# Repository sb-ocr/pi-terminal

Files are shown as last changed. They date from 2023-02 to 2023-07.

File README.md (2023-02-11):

# Pi Terminal

Watch the build video ↓

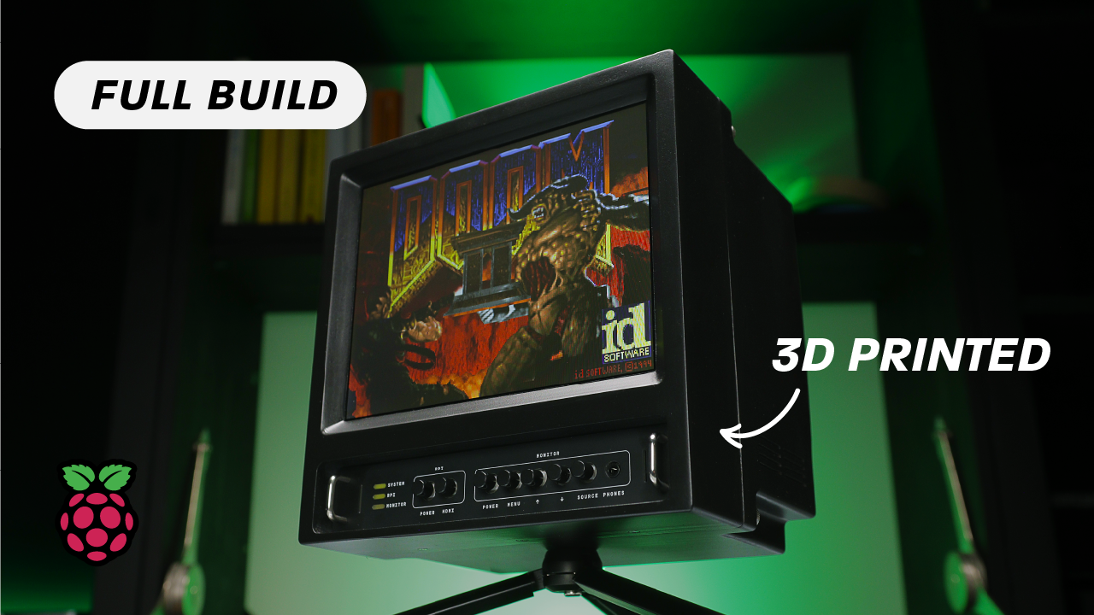
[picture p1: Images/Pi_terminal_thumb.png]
[](https://youtu.be/-QD0J8EfYqw)

Pi _Terminal is an all-in-one portable enclosure for the Raspberry Pi 4, featuring a 8 inch IPS screen, a low profile ice tower cooler, a UPS using two rechargeable 18650 lithium batteries and a HDMI switcher to use the display on it's own as a monitor.

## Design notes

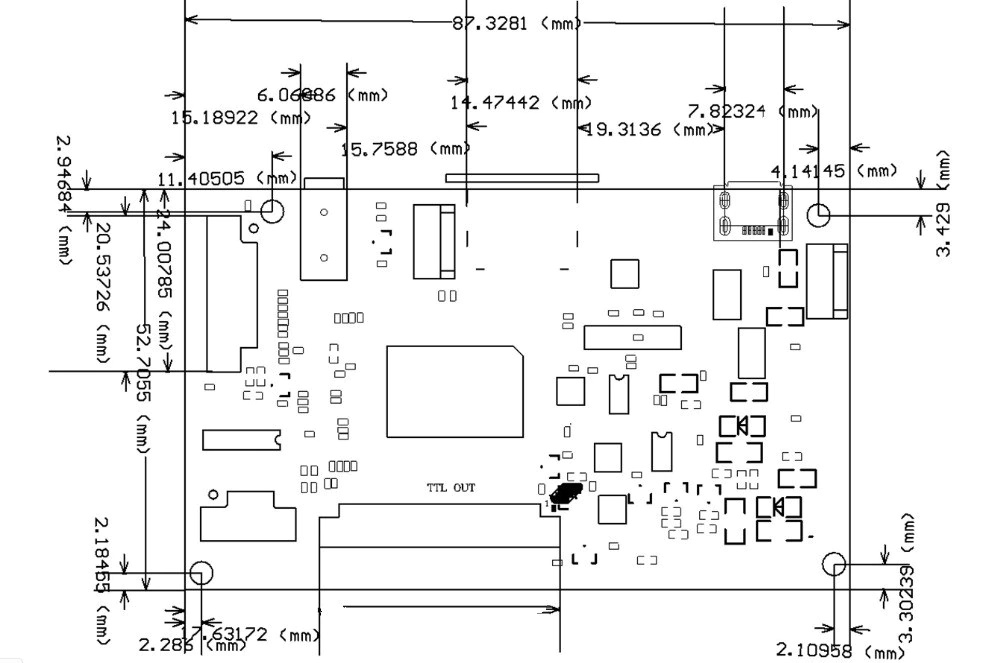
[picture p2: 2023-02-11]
Resources/Datasheets/Electronics/H08c82881f7de49e3b5ddad9591e3e27cJ.jpg

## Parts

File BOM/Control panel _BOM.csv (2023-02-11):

Qty | Value | Device | Package | Parts | Description | Manufacturer Part # | Digikey
2 | 100 Ohms | R-US_CHIP-0603(1608-METRIC) | RESC1608X60 | R1, R2 | Resistor Fixed - ANSI | WR06X101 JTL | 1292-WR06X101JTLCT-ND
2 | 4 Ohms | OWS142550TA4 | OWS-142550TA-4 | SPK1, SPK2 | 4 Ohms IoT Speaker Speaker 2 W 980 Hz ~ 20 kHz Top Rectangular | OWS-142550TA-4 | 3949-OWS-142550TA-4-ND
1 | - | PVA2EEH11.7NV2 | PVA2 | SW7 | Pushbutton Switch DPDT Keyswitch Through Hole | PVA2EEH1 1.7N V2 | 108-PVA2EEH11.7NV2-ND
6 | - | PVA1OAH11.2NV2 | PVA1 | SW1, SW2, SW3, SW4, SW5, SW6 | Pushbutton Switch DPST-NO Keyswitch Through Hole | PVA1 OA H1 1.2N V2 | 401-1133-ND
3 | - | CHIP-FLAT-G_1206 | LEDC3216X75N_FLAT-G | D1, D2, D3 | Green 567nm LED Indication - Discrete 2.1V 1206 (3016 Metric) | PG1101W-TR | 404-1046-1-ND
2 | - | STX-3790-5NSTX-3790-5N_KYC | STX-3790-5N_KYC | J1, J2 | 3.50mm (0.141", 1/8", Mini Plug) - Headphone Phone Jack Stereo (3 Conductor, TRS) Connector Solder | STX-3790-5N | 2092-STX-3790-5N-ND
1 | - | PINHD-2X10 | 2X10 | JP1 | Connector Header Through Hole 20 position 0.100" (2.54mm) | PREC010DAAN-RC | S2012EC-10-ND
1 |  | PINHD-2X2 | 2X2 | JP2 | Connector Header Through Hole 4 position 0.100" (2.54mm) | PREC002DAAN-RC | S2012EC-02-ND
7 | Black |  |  |  | Round Keyswitch Switch Cap Black Snap Fit | PV BK | 401-1148-ND

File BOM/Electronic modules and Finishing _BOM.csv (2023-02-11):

Qty | Item | Link | Link (alt)
Electronics
1 | Raspberry Pi 4 | https://rpilocator.com/
1 | Raspberry Pi Low-Profile CPU Cooler | https://geni.us/jZGuZt9
1 | Pi-UpTime UPS 2.0 | https://geni.us/zOOjE
2 | 2 × unprotected 18650 Li-Ion — 3400mAh
1 | IPS LCD 8 inch HJ080IA-01E with Driver Board | https://geni.us/ZfU1Y | https://s.click.aliexpress.com/e/_DmC2qmH
1 | HDMI Switcher 2 in 1 Out | https://geni.us/OfXlV
 | Hook-up wire | https://geni.us/8hiS
 | Dupont Connectors | https://geni.us/AMdor
1 | Micro HDMI to Standard Plug | https://www.adafruit.com/product/3557 | https://s.click.aliexpress.com/e/_DeT0a9b
1 | Micro HDMI to Standard Socket | https://www.adafruit.com/product/3557 | https://s.click.aliexpress.com/e/_DeT0a9b
1 | Standard HDMI Plug to Socket | https://www.adafruit.com/product/3557 | https://s.click.aliexpress.com/e/_DeT0a9b
1 | Standard HDMI Plug to Plug | https://www.adafruit.com/product/3557 | https://s.click.aliexpress.com/e/_DeT0a9b
1 | Micro to Micro USB cable (short)
1 | 3.5mm Audio cable (short)
Finishing
1 | Spool of PLA | https://geni.us/XkGsy
 | Assorted Grits Sandpaper | https://geni.us/turnM3
 | Glazing and Spot Putty | https://geni.us/3jiw9
 | Filler Primer (sandable) | https://geni.us/1BAKZ
 | Spray Paint | https://geni.us/I7qjJ
 | ‎Flat Matte Clear Coat | https://geni.us/Cywvbo

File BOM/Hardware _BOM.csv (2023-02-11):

Quantity | Description | McMaster Carr # | Amazon
1 | Heat-Set Inserts for Plastic 1/4"-20 Thread Size, 0.3" Installed Length, Brass | 93365A160
8 | Heat-Set Inserts for Plastic Brass, M4 x 0.70 mm Thread Size, 7.900 mm Installed Length | 94180A353
21 | Heat-Set Inserts for Plastic Brass, M2.5 x 0.45 mm Thread Size, 3.4 mm Installed Length | 94180A321
2 | Round Pull Handle 304 Stainless Steel, 3/4" Mounting Hole Center-to-Center Width, 1/2" Projection | 1726A112
4 | Flared-Collar Knurled-Head Thumb Screw M4 x 0.70 mm Thread Size, 10 mm Long | 99607A276
13 | Socket Head Screw M2.5 x 0.45 mm Thread, 5 mm Long | 91292A009 | https://geni.us/t4BmSQ
5 | Socket Head Screw M2.5 x 0.45 mm Thread, 20 mm Long | 91292A019 | https://geni.us/t4BmSQ
3 | Socket Head Screw M2.5 x 0.45 mm Thread, 8 mm Long | 91292A012 | https://geni.us/t4BmSQ
3 | Flat Head M2.5 x 5 - 6 mm Long | 93395A173
 | M2.5 Nylon Spacer Standoffs |  | https://geni.us/jIyiM

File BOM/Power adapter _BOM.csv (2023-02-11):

Qty | Value | Device | Package | Parts | Description | Manufacturer Part # | Digikey
2 |  | USB4125-GF-A_REVA2 | GCT_USB4125-GF-A_REVA2 | J1, J2 | USB-C (USB TYPE-C) Receptacle Connector 24 (6+18 Dummy) Charging only | USB4125-GF-A | 2073-USB4125-GF-ACT-ND
1 |  | 10118192-0002LF | AMPHENOL_10118192-0002LF | J3 | USB - micro B USB 2.0 Receptacle Connector 5 Position Surface Mount, Right Angle | 10118192-0002LF | 609-5379-1-ND
1 |  | PINHD-1X2 | 1X2 | JP1 | Connector Header Through Hole 2 position 0.100" (2.54mm) | PREC002SAAN-RC | S1012EC-02-ND
2 | 5K1 | R-US_CHIP-0603(1608-METRIC) | RESC1608X60 | R1, R2 | 5.1 kOhms ±5% 0.1W, 1/10W Chip Resistor 0603 (1608 Metric) | RC0603JR-075K1L | 311-5.1KGRCT-ND
1 |  | 2828XX-2282837-2 | TERMBLK_508-2N | U1 | 2 Position Wire to Board Terminal Block Horizontal with Board | 282837-2 | A113320-ND
1 |  | SPST |  |  | Rocker Switch SPST 6A (AC) 125 V Panel Mount, Snap-In | PRK22J5BBBNN | CH864-ND
1 |  | 1 x 2 |  |  | Shunt Connector Black Open Top 0.100" (2.54mm) Gold | QPC02SXGN-RC | S9337-ND

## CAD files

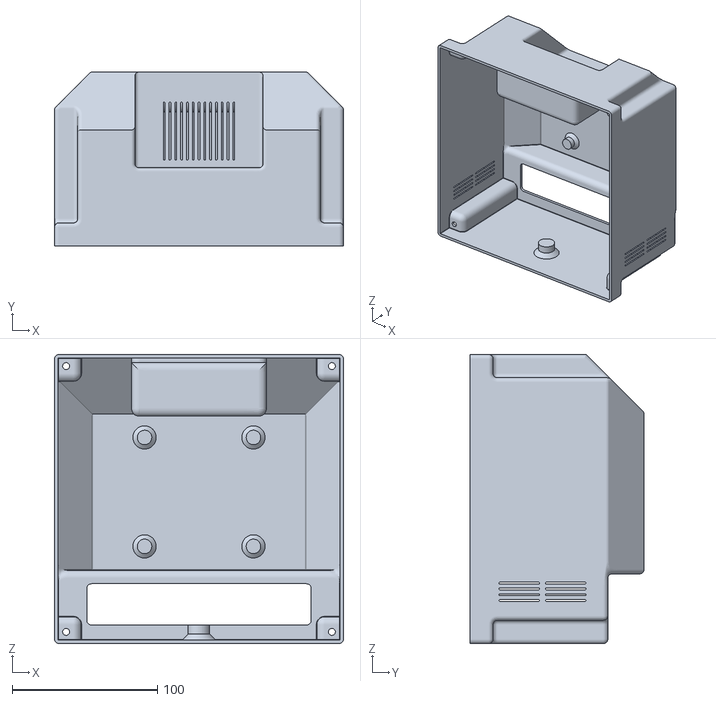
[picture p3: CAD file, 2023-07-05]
STLs/Back Shell.stl
199.0 x 120.0 x 199.0

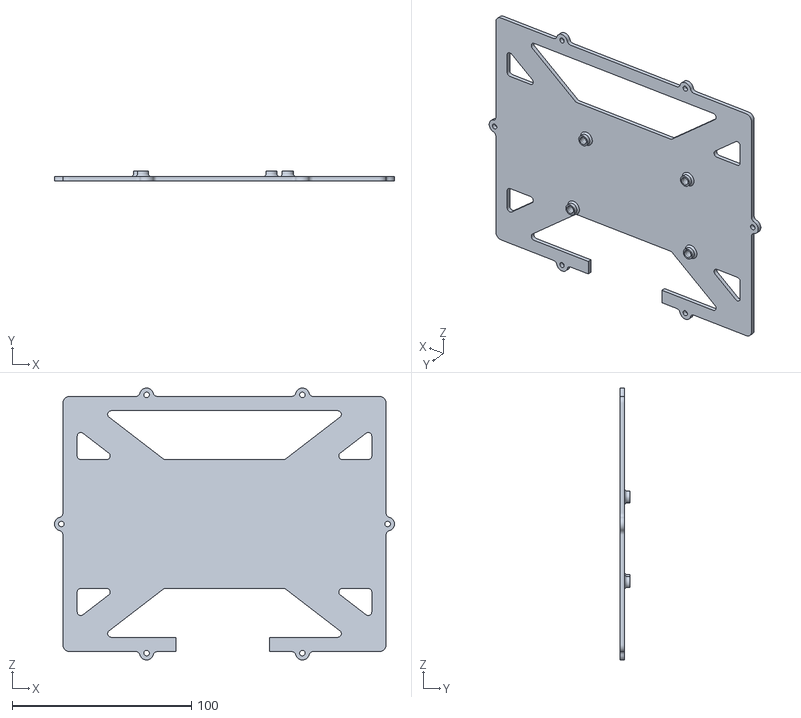
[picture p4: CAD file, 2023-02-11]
STLs/Screen Back Plate.stl
189.9 x 5.40 x 151.9

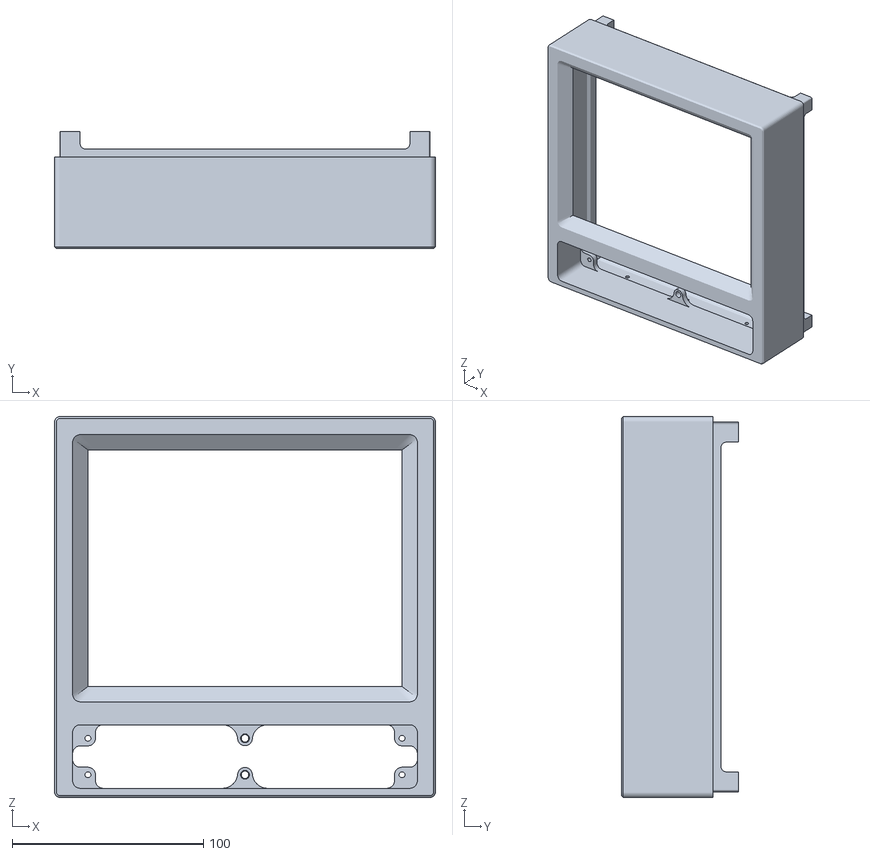
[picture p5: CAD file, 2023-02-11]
STLs/Front Bezel.stl
199.0 x 61.4 x 199.0

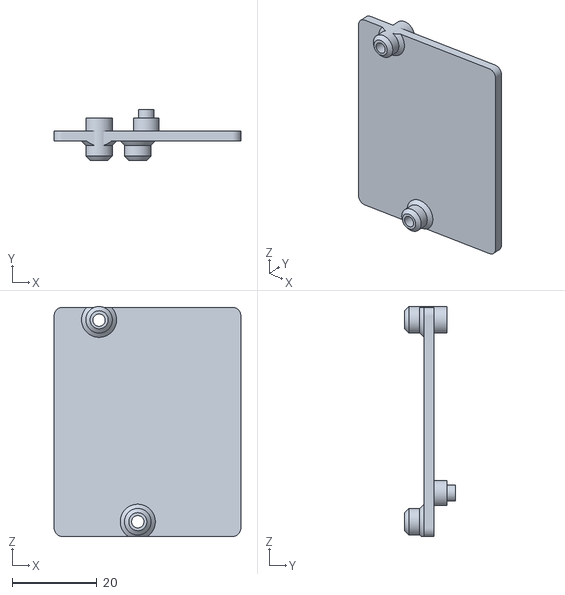
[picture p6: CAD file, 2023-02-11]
STLs/HDMI Switch Plate.stl
44.0 x 11.9 x 54.2

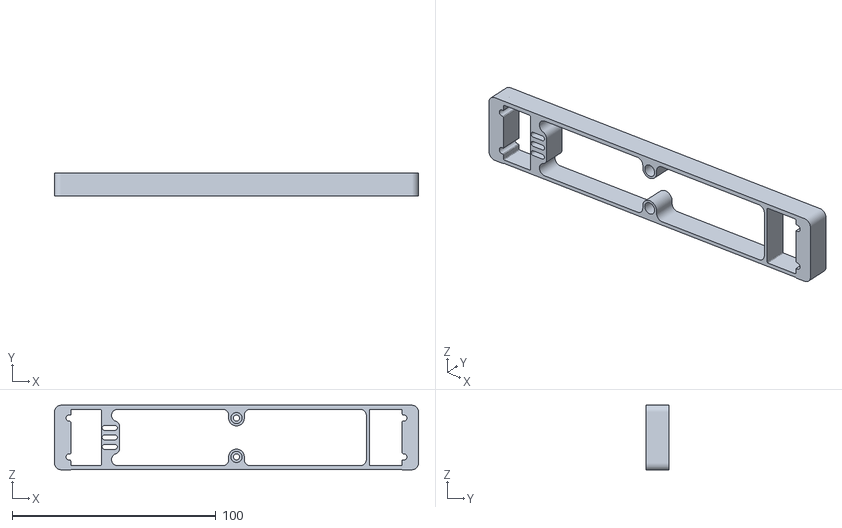
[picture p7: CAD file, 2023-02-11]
STLs/Control Panel Support.stl
178.5 x 11.1 x 31.7

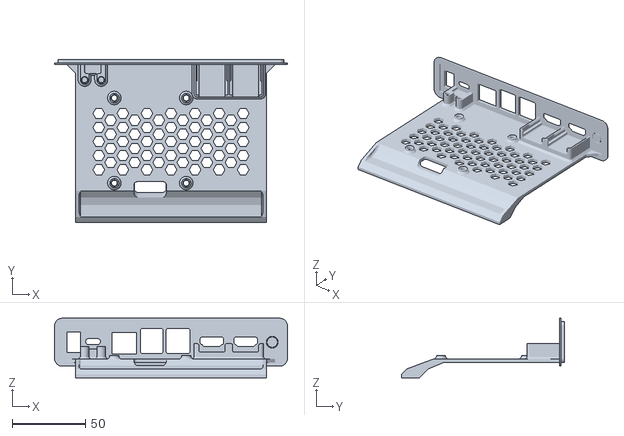
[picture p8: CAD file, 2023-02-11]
STLs/PCB and IO Plate.stl
158.8 x 111.4 x 40.6

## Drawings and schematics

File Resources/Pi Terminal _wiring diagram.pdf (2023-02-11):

11

10

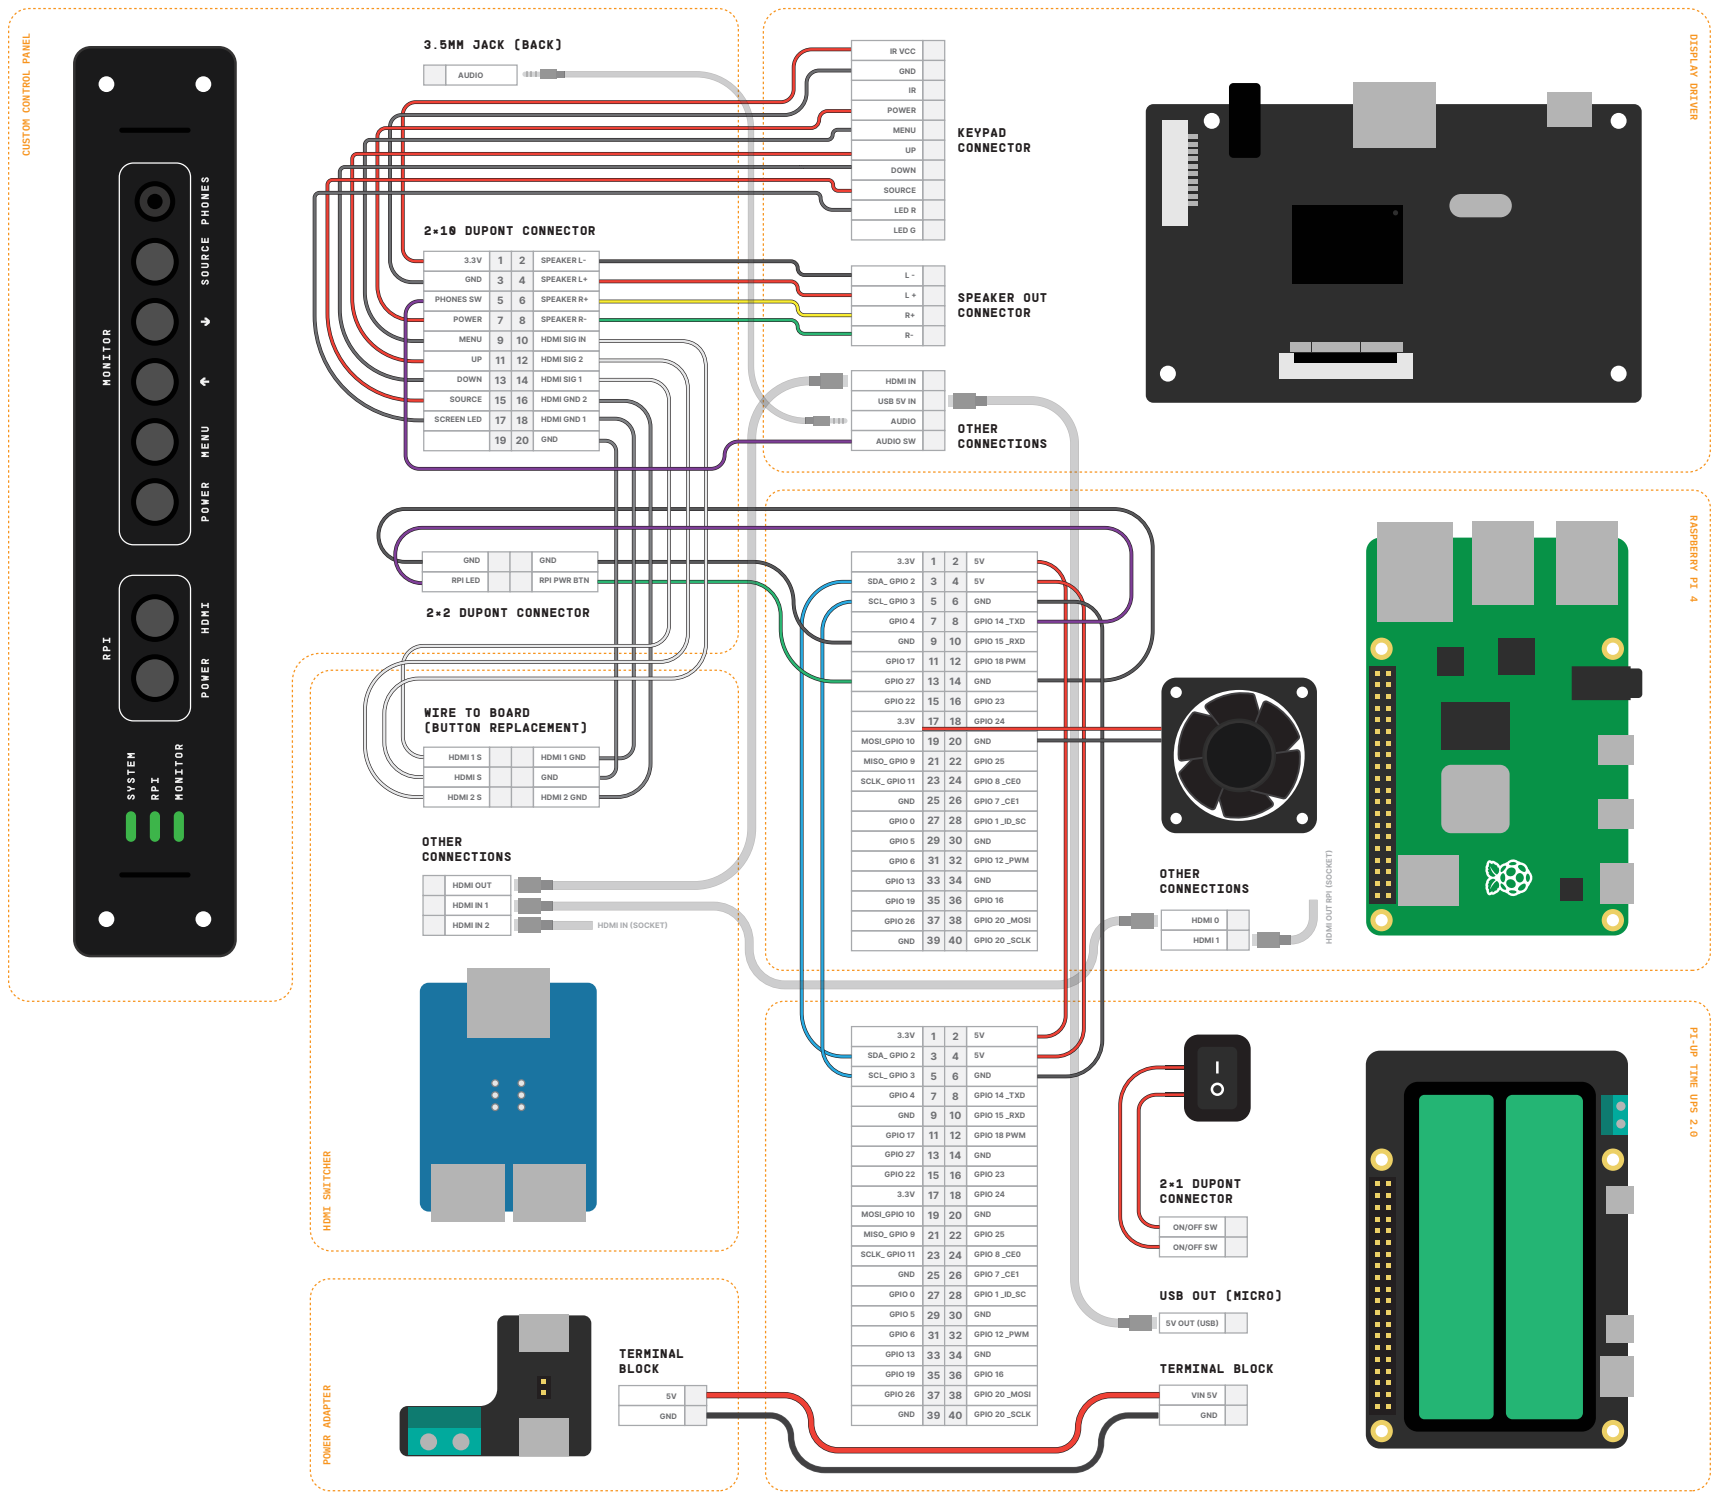
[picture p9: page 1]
SPEAKER L-; SPEAKER L+; SPEAKER R+; SPEAKER R-; HDMI SIG IN; HDMI SIG 2; HDMI SIG 1; HDMI GND 2; HDMI GND 1; GND; PHONES SW; POWER; MENU; DOWN; SOURCE; SCREEN LED; GPIO 14 _TXD; GPIO 15 _RXD; GPIO 18 PWM; GPIO 23; GPIO 24; GPIO 25; GPIO 8 _CE0; GPIO 7 _CE1; GPIO 1 _ID_SC; GPIO 12 _PWM; GPIO 16; GPIO 20 _MOSI; GPIO 20 _SCLK; SDA_ GPIO 2; SCL_ GPIO 3; GPIO 4; GPIO 17; GPIO 27; GPIO 22; MOSI_GPIO 10; MISO_ GPIO 9; SCLK_ GPIO 11; GPIO 0; GPIO 5; GPIO 6; GPIO 13; GPIO 19; GPIO 26; HDMI OUT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

CUSTOM CONTROL PANEL

DISPLAY DRIVER RASPBERRY PI 4 PI-UP TIME UPS 2.0

RPI PWR BTN

WIRE TO BOARD
(BUTTON REPLACEMENT)

HDMI OUT RPI (SOCKET)

HDMI IN (SOCKET)

HDMI SWITCHER POWER ADAPTER

ON/OFF SW

USB OUT (MICRO)

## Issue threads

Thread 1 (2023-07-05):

Missing Back Shell File

augustalexander, 2023-07-05:
Looks like the Back Shell STL was deleted and is now missing in the repo.

sb-ocr, 2023-07-05:
Thanks for pointing this out. I just uploaded it again.

Closed 2023-07-05.

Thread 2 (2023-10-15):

PCB Fabrication Information

alevan10, 2023-10-15:
I've tried sending the zip files here, as well as the project you have uploaded to PCBWay to try and get these fabricated by them. However, as a someone new to PCB fabrication, I don't know any of the correct settings, nor can I edit the gerber files myself with any confidence. PCBWay replied back that, specifically, the information in the Front Panel PCB don't make it clear what they should do with the three openings for the LCDs. Do you have additional information, or updated files that you might be able to post here, or any guidance on how best to get these produced. Everything else you have has worked great!

sb-ocr, 2023-10-15:
Layers: 2
Material: FR4
Thickness: 1.6mm
Solder Mask: Black (or choose the color you want)

If you're ordering from PCBWay, you can keep the rest of the options as default.

I'm not sure what LCDs you are referring to, but the '3 slots' on the front panel are diffusion for the LEDs. The board has the copper and solder mask removed from those spots on both sides, only FR4 is exposed and let the light shines through (see the image below).

Best of luck!

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

alevan10, 2023-10-16:
lol, I meant LEDs. Thank you very much! I'm really looking forward to working through this project!

Closed 2023-10-15.

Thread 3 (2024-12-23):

Fusion 360 project files

kovapatrik, 2024-12-23:
Hello!

I love this project and really like how you designed the case for it. Currently, I'm creating a miniature version of a CRT TV (just for decoration, so it won't be that fancy as your project is:D) and I would really use the design files from your project.

Is it possible you can share these?

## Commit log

2023-02-11 pi term video upload
    [Control Panel Support.stl, Control panel _BOM.csv, Electronic modules and Finishing _BOM.csv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]
2023-07-05 Back Shell STL was deleted by mistake
    [Back Shell.stl]
